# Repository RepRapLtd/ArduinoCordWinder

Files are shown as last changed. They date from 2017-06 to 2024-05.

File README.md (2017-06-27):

An Arduino-controlled cord winder for moving things.

(Original application - release chickens from their coop at dawn.)

This consists of a laser-cut box held together with 3D pronted parts.  Inside is a cylindrical winder driven by a geared motor.  These are controlled by an Arduino Uno with a shield that drives the motor.

As distributed it is powered by 12 volts, and takes an opto-isolated input from a solar cell (assumed also to be charging the 12 volt battery).  When the solar voltage rises above a threshold the winder runs until a marker on the wound cord triggers a microswitch, causing it to stop.

There are also push buttons to wind and unwind the cord manually.

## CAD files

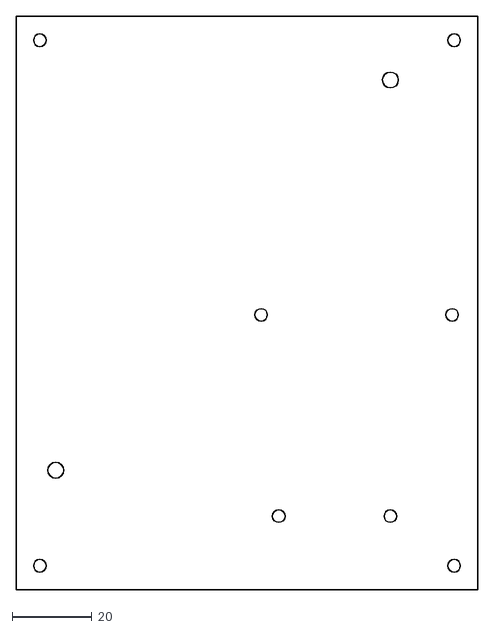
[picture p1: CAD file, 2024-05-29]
DXFs/back.dxf
116.0 x 144.0

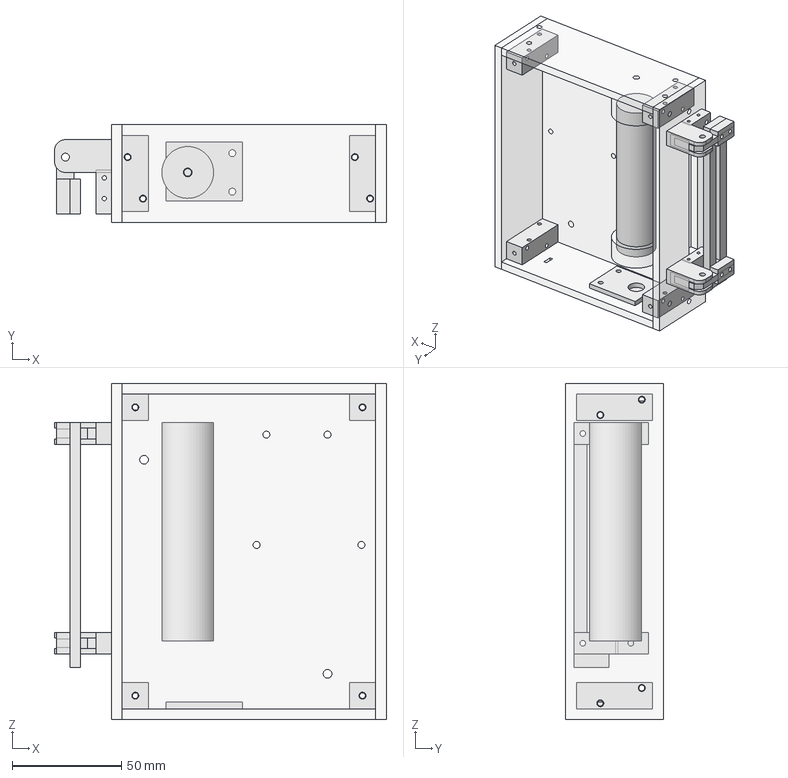
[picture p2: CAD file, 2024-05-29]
Mechanics/chicken-door-winder.fcstd
152.0 x 45.0 x 154.0 mm
top-x
string-slot-c
bottom-a
right-a
back-a
left-a
corner-block
corner-block001
corner-block002
corner-block003
motor-spacer
switch-rocker-f
switch-rocker-g
switch-hinge-j
switch-hinge-k
winder-end-free
winder-end-motor
winder

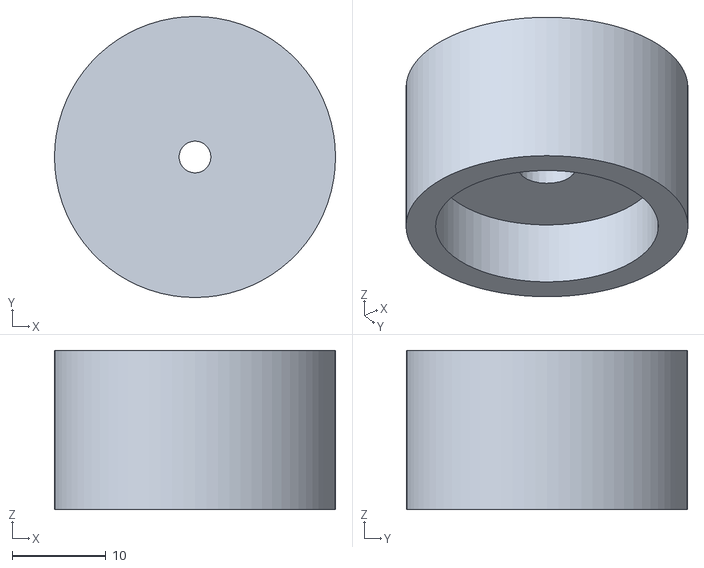
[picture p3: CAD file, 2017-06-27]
STLs/winder-end-free-1-off.stl
30.0 x 30.0 x 17.0

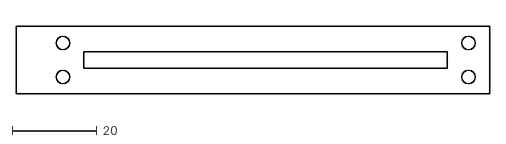
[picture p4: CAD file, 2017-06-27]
DXFs/string-slot.dxf
112.0 x 16.0

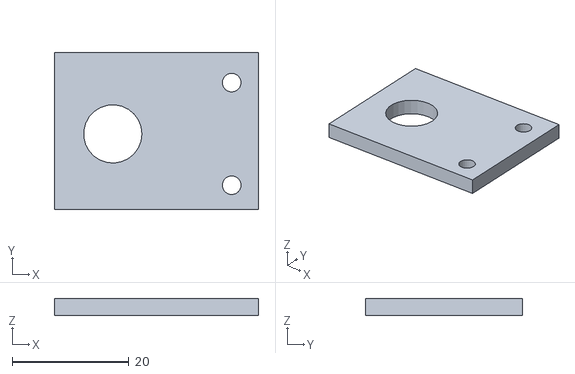
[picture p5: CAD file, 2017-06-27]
STLs/motor-spacer-1-off.stl
35.0 x 27.0 x 3.00

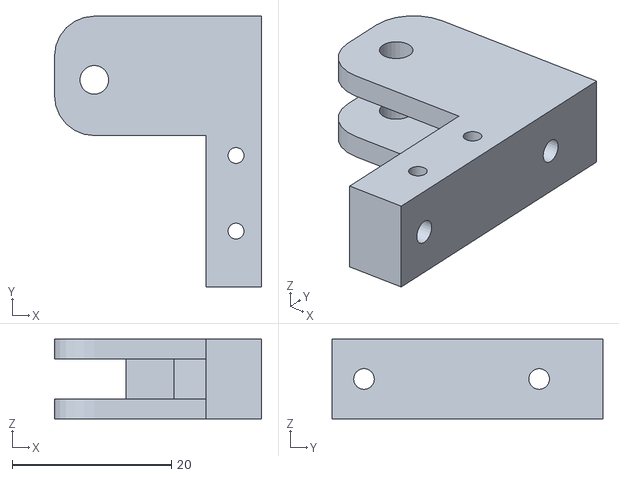
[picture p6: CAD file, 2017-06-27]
STLs/switch-hinge-2-off.stl
26.0 x 34.0 x 10.0

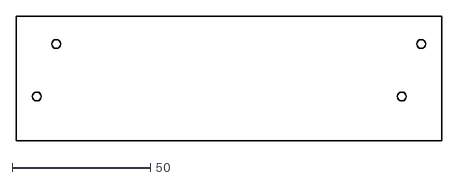
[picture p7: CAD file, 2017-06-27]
DXFs/top.dxf
154.0 x 45.0

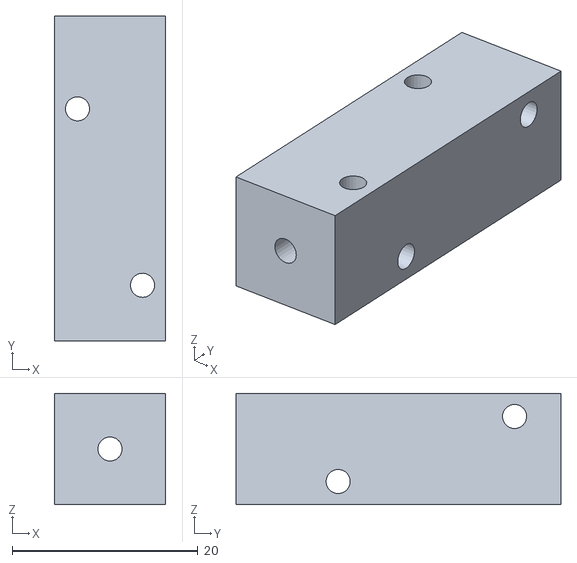
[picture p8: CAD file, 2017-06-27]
STLs/corner-block-4-off.stl
12.0 x 35.0 x 12.0

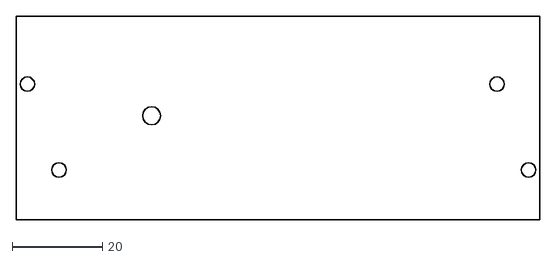
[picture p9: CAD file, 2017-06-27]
DXFs/right.dxf
116.0 x 45.0

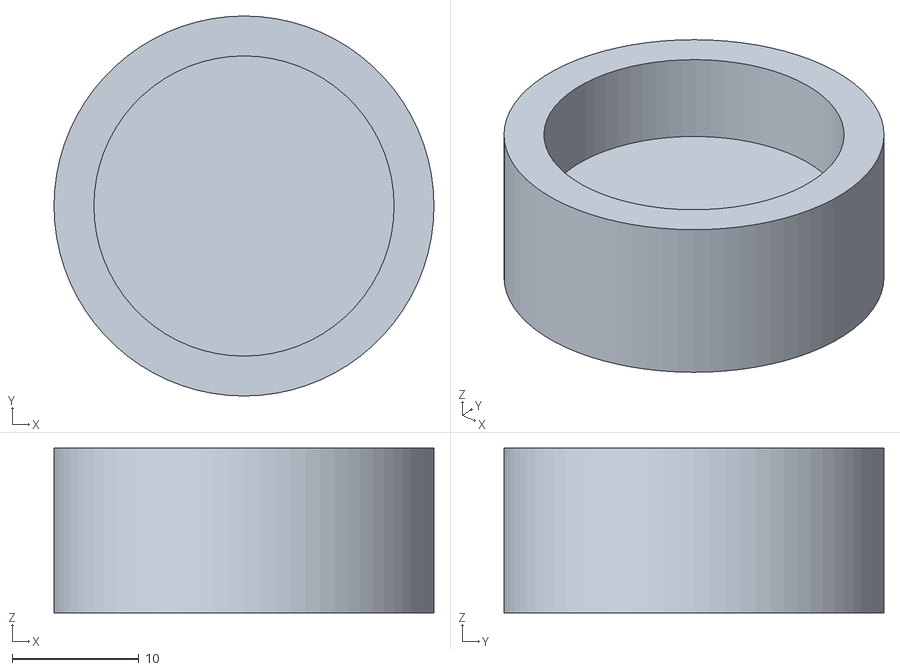
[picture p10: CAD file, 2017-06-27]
STLs/winder-end-motor-1-off.stl
30.0 x 30.0 x 13.0

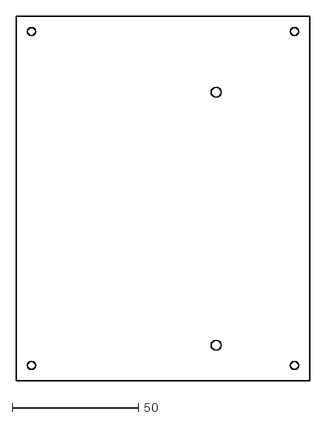
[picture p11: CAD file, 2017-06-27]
DXFs/front.dxf
116.0 x 144.0

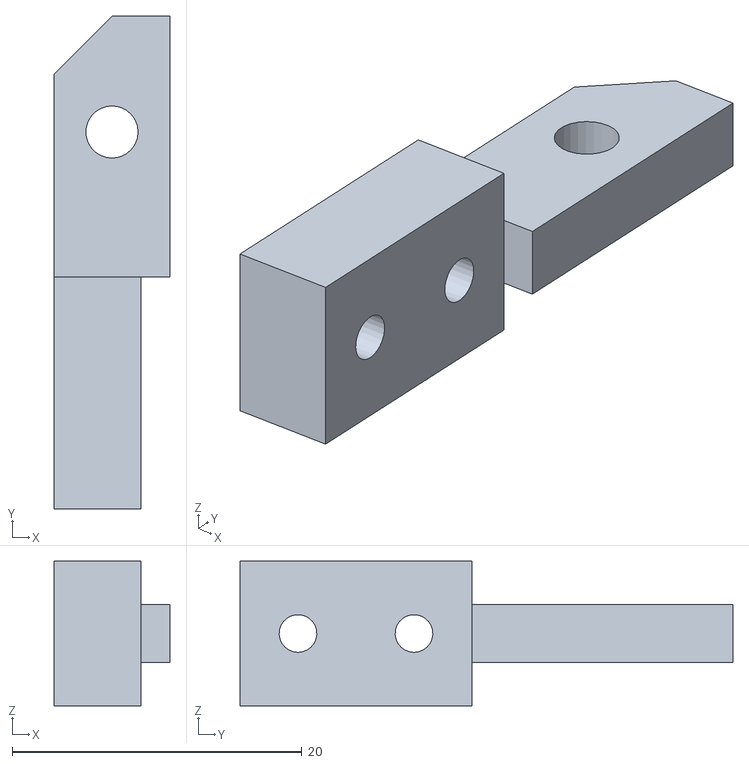
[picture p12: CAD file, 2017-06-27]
STLs/switch-rocker-2-off.stl
8.00 x 34.0 x 10.0

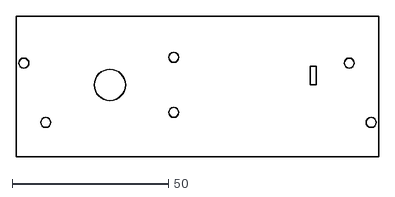
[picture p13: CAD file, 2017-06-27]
DXFs/left.dxf
116.0 x 45.0

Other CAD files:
DXFs/lasercut-parts.dxf

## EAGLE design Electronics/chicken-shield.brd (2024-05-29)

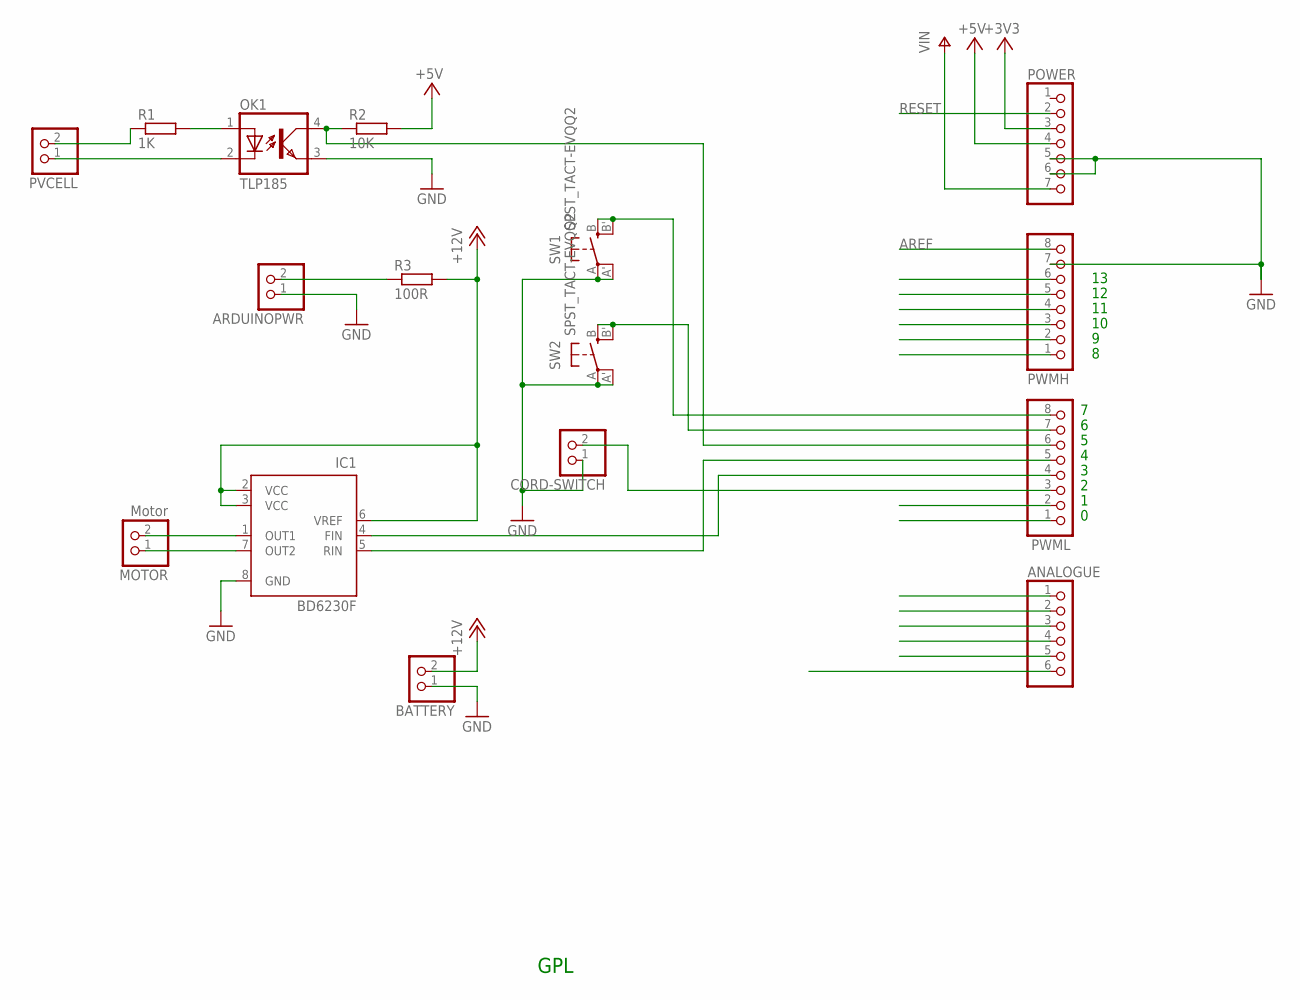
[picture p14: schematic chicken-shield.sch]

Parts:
ANALOGUE: PINHD-1X6; 1X06
ARDUINOPWR: PINHD-1X2; 1X02
BATTERY: PINHD-1X2; 1X02
CORD-SWITCH: PINHD-1X2; 1X02
IC1: BD6230F; SOP8
MOTOR: Motor; 1X02
OK1: TLP185; MINI-FLAT-4
POWER: PINHD-1X7; 1X07
PVCELL: PINHD-1X2; 1X02
PWMH: PINHD-1X8; 1X08
PWML: PINHD-1X8; 1X08
R1: 1K; M0805
R2: 10K; M0805
R3: 100R; 0204/7
SW1, SW2: SPST_TACT-EVQQ2; EVQ-Q2

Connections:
+3V3: POWER.3
+5V: POWER.4, R2.2
+12V: BATTERY.2, IC1.2 (VCC), IC1.3 (VCC), IC1.6 (VREF), R3.2
A0: ANALOGUE.1
A1: ANALOGUE.2
A2: ANALOGUE.3
A3: ANALOGUE.4
A4: ANALOGUE.5
A5: ANALOGUE.6
AREF: PWMH.8
DIG0_RX: PWML.1
DIG1_TX: PWML.2
DIG2: IC1.5 (RIN), PWML.5
DIG3: IC1.4 (FIN), PWML.4
DIG4: CORD-SWITCH.2, PWML.3
DIG8: PWMH.1
DIG9: PWMH.2
DIG10: PWMH.3
DIG11: PWMH.4
DIG12: PWMH.5
DIG13: PWMH.6
GND: ARDUINOPWR.1, BATTERY.1, CORD-SWITCH.1, IC1.8 (GND), OK1.3 (EMIT), POWER.5, POWER.6, PWMH.7, SW1.A, SW1.A' (P1), SW2.A, SW2.A' (P1)
unnamed: OK1.2 (C), PVCELL.1
unnamed: OK1.1 (A), R1.2
unnamed: IC1.1 (OUT1), MOTOR.2
unnamed: ARDUINOPWR.2, R3.1
unnamed: IC1.7 (OUT2), MOTOR.1
unnamed: PVCELL.2, R1.1
unnamed: OK1.4 (COL), PWML.6, R2.1
unnamed: PWML.8, SW1.B (S), SW1.B' (S1)
unnamed: PWML.7, SW2.B (S), SW2.B' (S1)
RESET: POWER.2
VIN: POWER.7

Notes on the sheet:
GPL

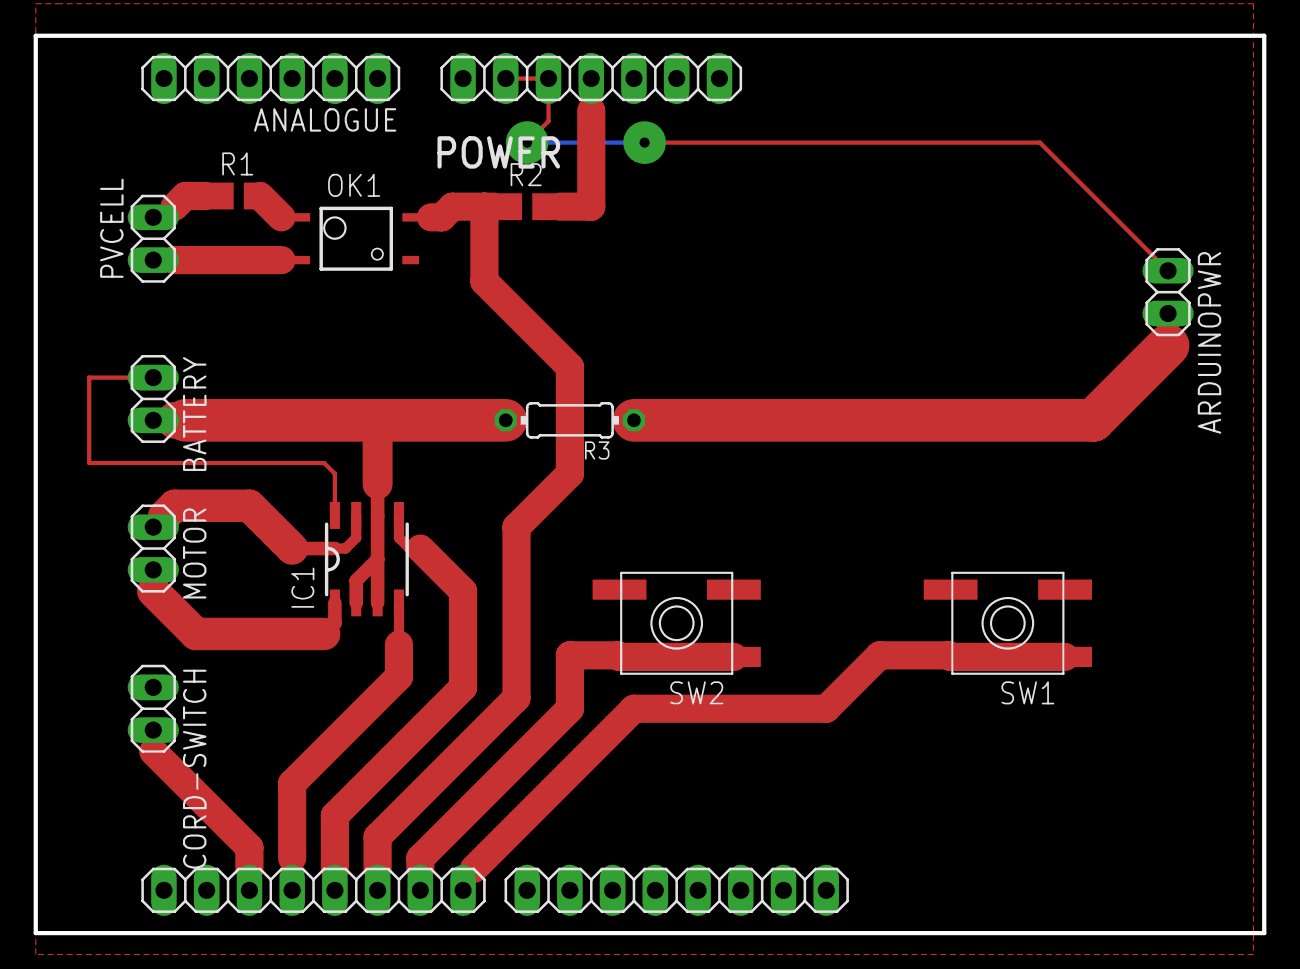
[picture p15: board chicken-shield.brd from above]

Board: 2 copper layers, 73.0 x 53.3 mm, 16 parts (0 on the bottom side), 15 nets.

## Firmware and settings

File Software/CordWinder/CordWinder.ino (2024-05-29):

/* 
 *  Control program for the Cord Winder
 *  Arduino Uno
 *  
 *  Adrian Bowyer
 *  RepRap Ltd
 *  
 *  9 July 2017
 */

const int ledPin =  13;

// Motor pins

const int motorPlus = 3;
const int motorMinus = 4;
const int sensorSwitch = 2;
const int lightSensor = 5;
const int upSwitch = 6;
const int downSwitch = 7;

// For the motor

const int pwm = 100;

// Status of the device

bool doorClosed = true;
bool openAtDawn = false;


// Turn the motors off

void Stop()
{
  digitalWrite(motorPlus, 1);
  digitalWrite(motorMinus, 1);
  if(ledPin >= 0) digitalWrite(ledPin, 0);
}


// Run the motor to drop the door

void Close()
{
  digitalWrite(motorMinus, 0);
  analogWrite(motorPlus, pwm);
  if(ledPin >= 0) digitalWrite(ledPin, 1);
}


// Run the motor to raise the door

void Open()
{
  if(digitalRead(sensorSwitch))
  {
    Stop();
    return;
  }
  analogWrite(motorPlus, pwm);
  digitalWrite(motorMinus, 1);
  if(ledPin >= 0) digitalWrite(ledPin, 1);
}


// Initialisation

void setup() 
{
  // If we have a LED, allow it to be used

  if(ledPin >= 0) pinMode(ledPin, OUTPUT);

  // Motor pins are output.

  pinMode(motorPlus, OUTPUT);
  pinMode(motorMinus, OUTPUT);
  Stop();

  pinMode(sensorSwitch, INPUT);
  digitalWrite(sensorSwitch,1);
  pinMode(upSwitch, INPUT);
  digitalWrite(upSwitch,1);
  pinMode(downSwitch, INPUT);
  digitalWrite(downSwitch,1);
  pinMode(lightSensor, INPUT);
  doorClosed = true;
  openAtDawn = false;
}


void loop() 
{
  if(!digitalRead(upSwitch))
  {
    while(!digitalRead(sensorSwitch)) Open();
    doorClosed = false;
  }
  
  if(!digitalRead(downSwitch))
  {
    Close();
  } else
  {
    Stop();
    doorClosed = true;
  }
    
  if(!digitalRead(lightSensor) && doorClosed && openAtDawn)
  {
    while(!digitalRead(sensorSwitch))Open();
    doorClosed = false;
    openAtDawn = false;
  }
  
  if(digitalRead(lightSensor))
    openAtDawn = true;
}

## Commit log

2017-06-27 First commit.
    [back.dxf, chicken-door-winder.fcstd, chicken-shield.brd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]
2024-05-29 Bringing up to date
    [back.dxf, chicken-door-winder.fcstd, chicken-shield.brd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]
